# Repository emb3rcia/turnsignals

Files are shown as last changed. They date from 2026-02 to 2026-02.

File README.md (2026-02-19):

# turnsignals

Hello! This project is very simple, but to some people may be very needed, this is turnsignals module for PC steering wheels like logitech g29, made for HackClub's Blueprint program. It features USB-C (USB-FS standard) port for data and power and ESD protection on VBUS, DATA channels and CC channels! Firmware is given as whole STM32CubeIDE project. It is generated in STM32CubeMX and then the rest written in STM32CubeIDE

## Why i did this?

I want to get driving license soon. My biggest fear? Getting ticket for forgotting to signal a turn. My solution? Buy used PC steering wheel with pedals and gear shifter, make my own turnsignals and download some game where i can drive and use them. In this way i can make it my muscle memory.

# Images

Schematic

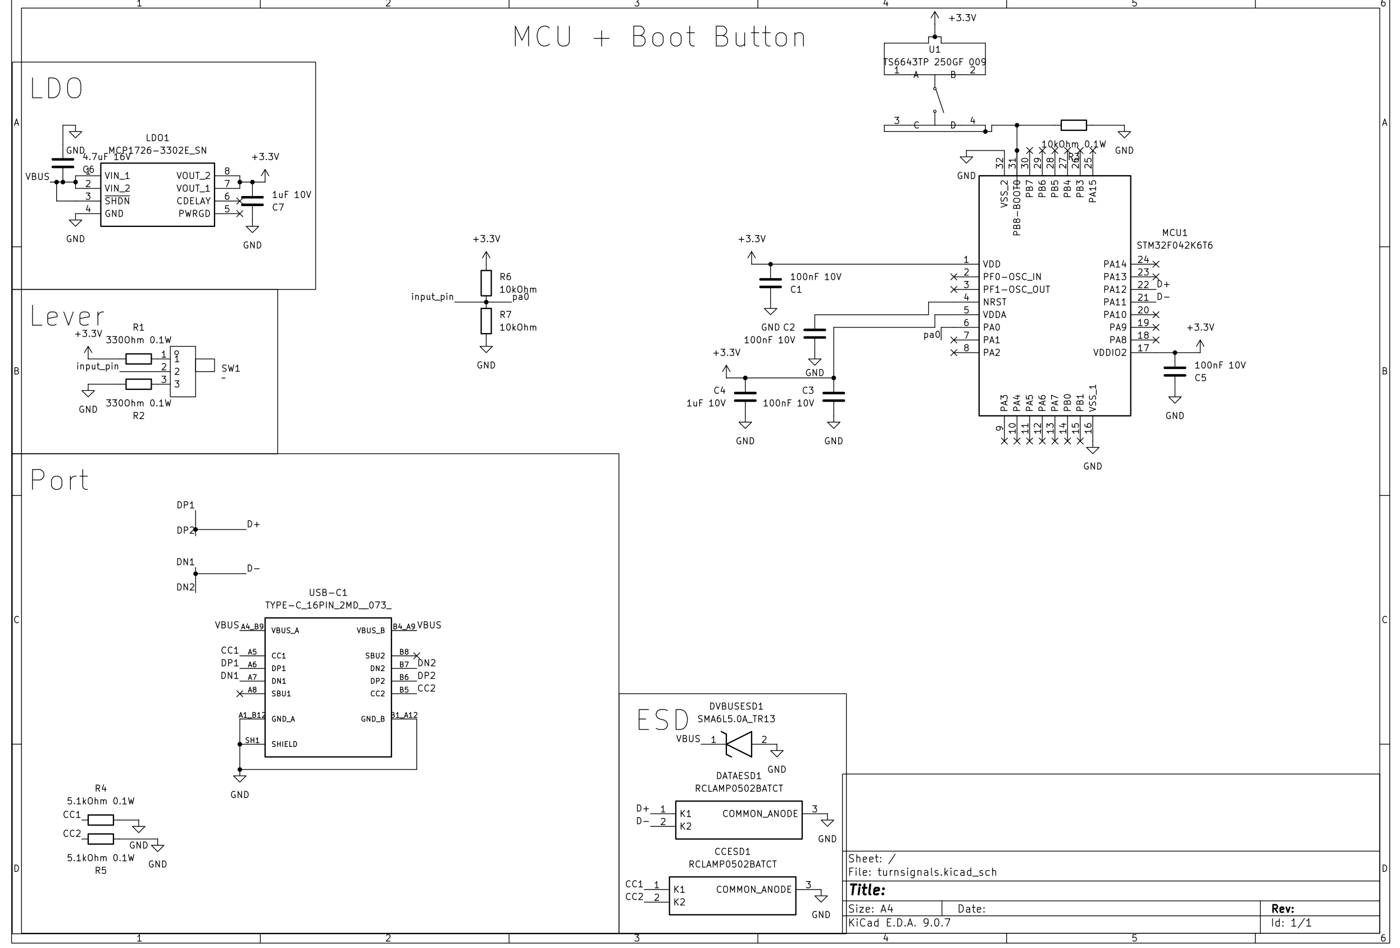
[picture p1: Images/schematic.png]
Schematic


PCB

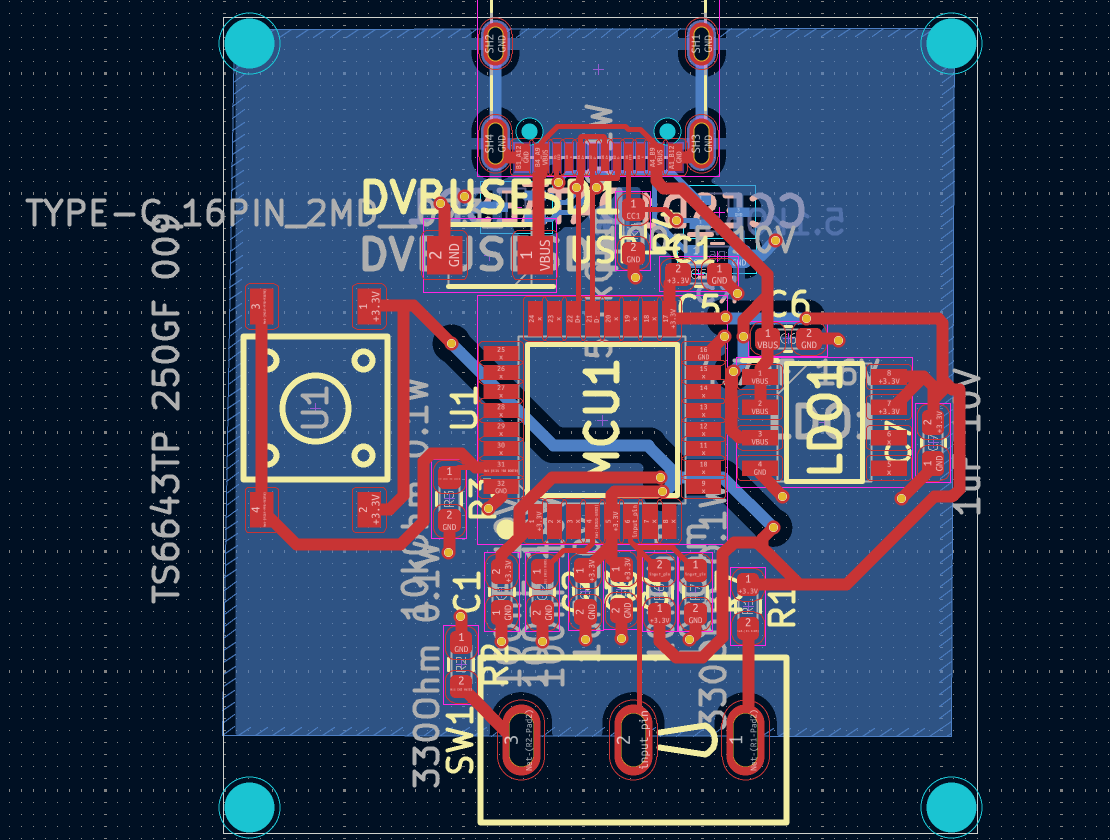
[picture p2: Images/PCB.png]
PCB


3D KiCad viewer

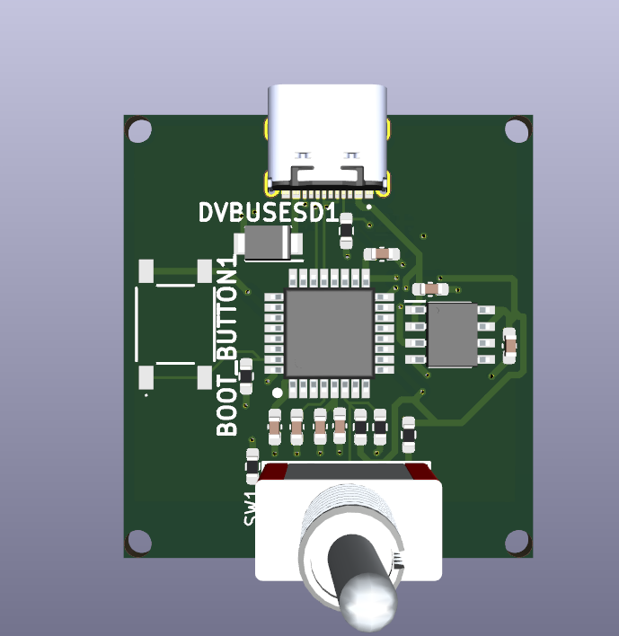
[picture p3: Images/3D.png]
3D


3D PCB

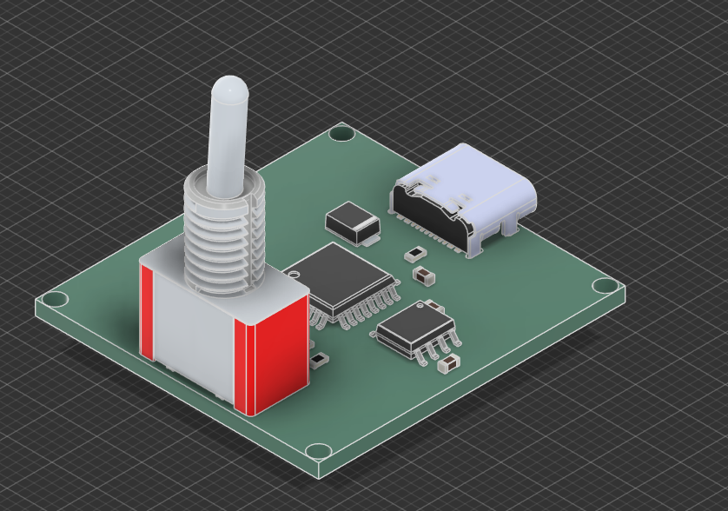
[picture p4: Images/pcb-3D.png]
3D PCB


3D Assembled

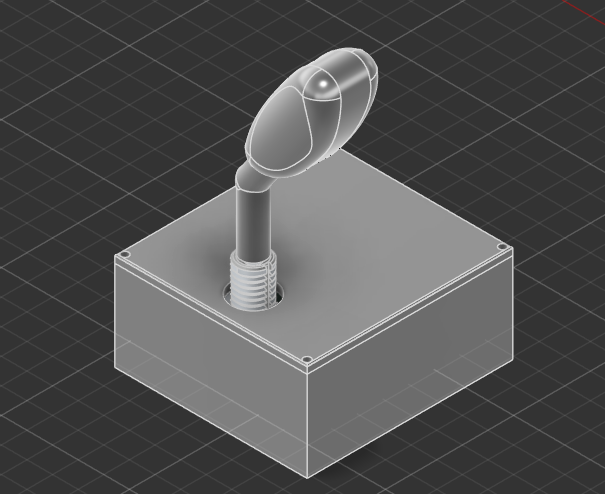
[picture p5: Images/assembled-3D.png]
3D Assembled


3D Lever

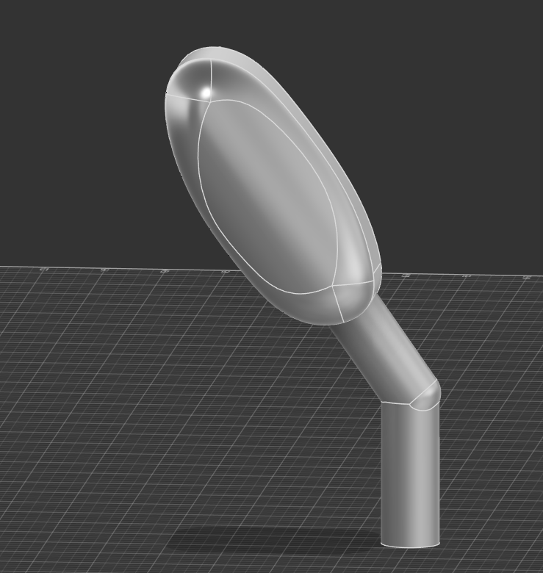
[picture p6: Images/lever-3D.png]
3D Lever


3D Case (top)

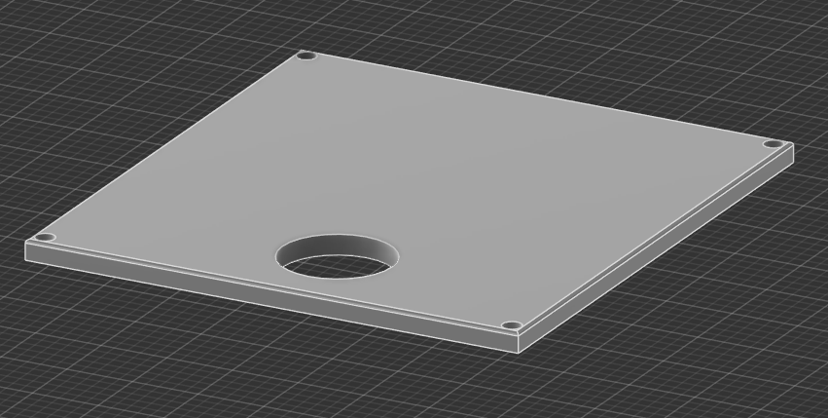
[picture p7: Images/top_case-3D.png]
3D Case


3D Case (bottom)
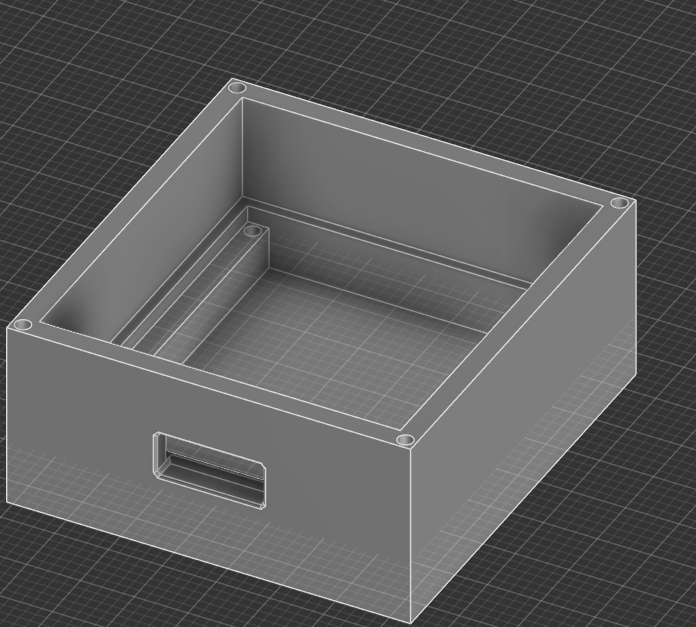
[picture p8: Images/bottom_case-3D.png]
3d Case


# Datasheets & part list
Here you can find datasheet for every part and exact part number for it i used:
- MCU: [STM Electronics STM32F042K6T6 LQFP-32 Package](Datasheets/STM32F042K6T6.pdf)
- USB-C Port: [SHOU HAN TYPE-C 16PIN 2MD(073)](Datasheets/TYPE-C-16PIN-2MD(073).pdf)
- DATA and CC lines ESD diodes: [Semtech RCLAMP0502BATCT](Datasheets/RCLAMP0502BATCT.pdf)
- VBUS line ESD diode: [Yageo SMA6L5.0A_TR13](Datasheets/SMA6L5.0A_TR13.pdf)
- 3.3V LDO: [Microchip MCP1726-3302E_SNVAO](Datasheets/MCP1726-3302E_SNVAO.pdf)
- 4.7uF 16V Capacitor: [Murata Electronics GRM188Z71C475KE21D](Datasheets/GRM188Z71C475KE21D.pdf)
- 1uF 10V Capacitor: Samsung Electro-Mechanics CL10A105KA8NNNC
- 100nF 10V Capacitor: [Vishay VJ0603Y104JXQCW1BC](Datasheets/VJ0603Y104JXQCW1BC.pdf)
- 5.1kOhm 0.1W Resistor: [Bourns CR0603-FX-5101ELF](Datasheets/CR0603-FX-5101ELF.pdf)
- 10Ohm 0.1W Resistor: [Vishay CRCW060310K0DHEAP](Datasheets/CRCW060310K0DHEAP.pdf)
- 300Ohm 0.1W Resistor: [GiantOhm GR0603J330RT5G00](Datasheets/GR0603J330RT5G00.pdf)
- BOOT button: [SHOU HAN TS6643TP 250gf 009](Datasheets/TS6643TP-250gf-009.pdf)
- Lever Toggle switch: [Dailywell 1MS1T1B1M1QES-5](Datasheets/1MS1T1B1M1QES-5.pdf)
# BOM
|Item |Description |Needed|Ordered|Why more/less? |Unit Price ($)|Total Price ($) |URL |
|---|---|---|---|---|---|---|---|
|ST STM32F042K6T6 |MCU |1 |1 |- |1.80$ |1.80$ |https://www.lcsc.com/product-detail/C69216.html |
|SEMTECH RCLAMP0502BATCT |CC and DATA lines esd |2 |0 |I have 3 left from other project |- |- |https://www.lcsc.com/product-detail/C117553.html |
|Littelfuse SMA6L5.0A |VBUS line esd |1 |1 |- |0.79$ |0.79$ |https://www.lcsc.com/product-detail/C1974860.html |
|MICROCHIP MCP1726-3302E/SN |3.3V LDO |1 |1 |- |2.22$ |2.22$ |https://www.lcsc.com/product-detail/C635928.html |
|muRata GRM188Z71C475KE21D |4.7uF capacitor |1 |0 |I have 9 left from other project |- |- |https://www.lcsc.com/product-detail/C389010.html |
|Samsung Electro-Mechanics CL10A105KA8NNNC|1uF capacitor |2 |50 |Minimal order size is 50 |0.0058$ |0.29$ |https://www.lcsc.com/product-detail/C5673.html |
|VISHAY VJ0603Y104JXQCW1BC |100nF decap capacitor |4 |5 |sold in increments of 5 |0.08$ |0.40$ |https://www.lcsc.com/product-detail/C3834925.html |
|SAMWHA CS1608X7R225K100NRB |2.2uF capacitor |2 |0 |I have 98 left from other project|- |- |https://www.lcsc.com/product-detail/C516003.html |
|BOURNS CR0603-FX-5101ELF |5.1kOhm 0.1w CC resistor |2 |0 |I have 8 left from other project |- |- |https://www.lcsc.com/product-detail/C2076779.html |
|VISHAY CRCW060310K0DHEAP |10kOhm pull-up/down resistor|2 |0 |I have 3 left from other project |- |- |https://www.lcsc.com/product-detail/C3917708.html |
|SHOU HAN TS6643TP 250gf 009 |BOOT and NRST button |2 |0 |I have 48 left from other project|- |- |https://www.lcsc.com/product-detail/C5342967.html |
|SHOU HAN TYPE-C 16PIN 2MD(073) |USB-C plug |1 |0 |I have 19 left from other project|- |- |https://www.lcsc.com/product-detail/C2765186.html |
|Shuntian PB1.6X4 |Mouting screws |4 |10 |minimal order size is 10 |0.04$ |0.42$ |https://www.lcsc.com/product-detail/C357374.html?s_z=n_1.6x4 |
|Dailywell 1MS1T1B1M1QES-5 |Lever Toggle switch |1 |1 |- |1.01$ |1.01$ |https://www.lcsc.com/product-detail/C496154.html?s_z=n_1MS1T1B1M1QES-5|
|PCB |PCB |1 |5 |5 is minimal order amount |- |2$+1.5$ delivery|https://jlcpcb.com/ |

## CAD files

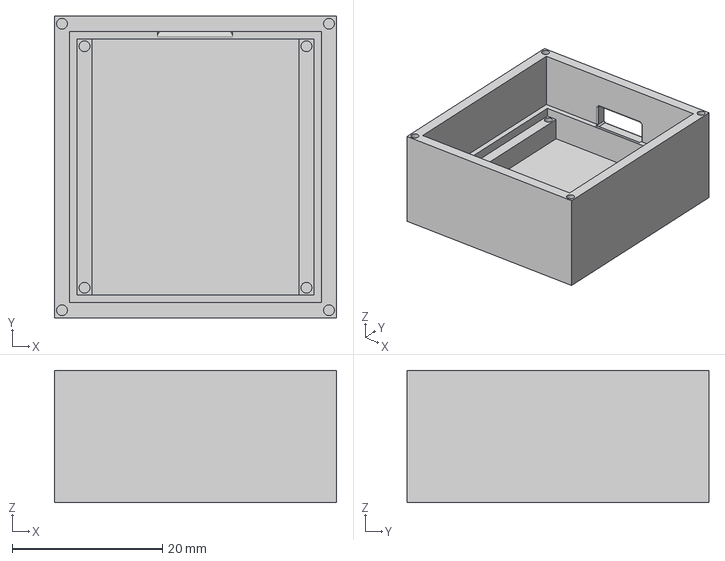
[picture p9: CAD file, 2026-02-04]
3D/bottom_case.step
37.5 x 40.1 x 17.6 mm

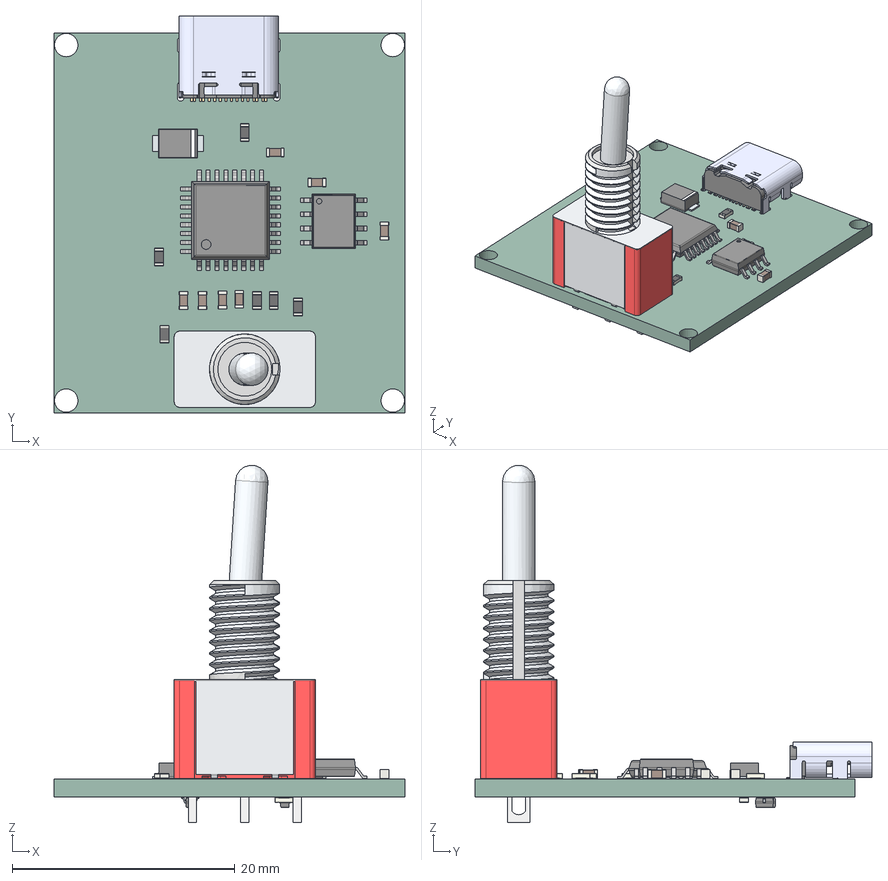
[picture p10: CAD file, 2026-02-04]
3D/pcb.step
31.5 x 35.6 x 32.1 mm
R_0603_1608Metric_1 x 7
C_0603_1608Metric_1 x 7
ASSEMBLY
ASSEMBLY_1
ASSEMBLY_2
TYPE-C 16PIN 2MD -073
toggle_switch_1ms1t1b1m1qes
ASSEMBLY_3 x 2
turnsignals_PCB

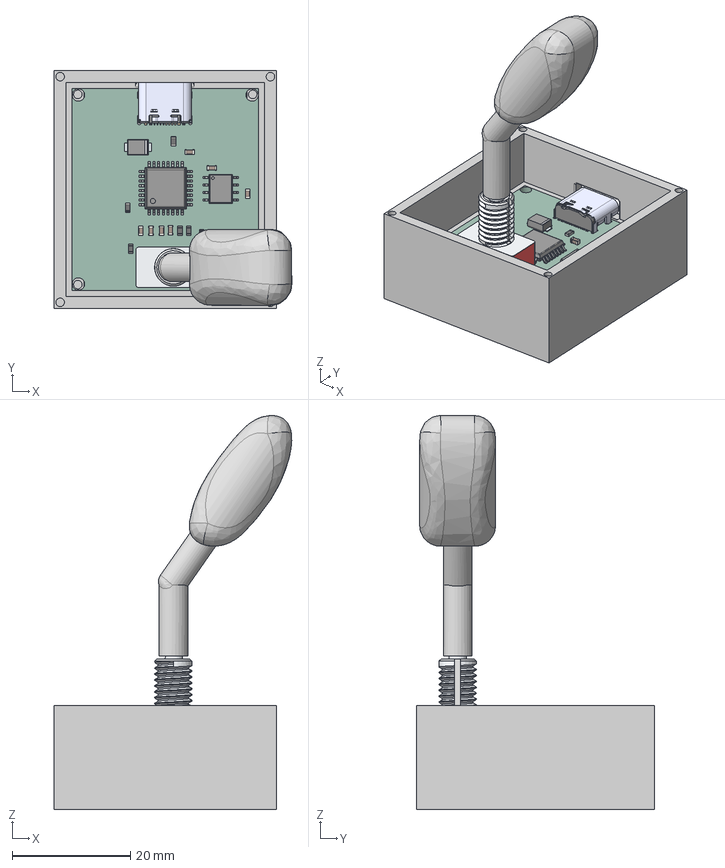
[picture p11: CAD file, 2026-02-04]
3D/turnsignals.step
40.2 x 40.1 x 66.6 mm
bottom_case
R_0603_1608Metric_1 x 7
C_0603_1608Metric_1 x 7
ASSEMBLY
ASSEMBLY_1
ASSEMBLY_2
TYPE-C 16PIN 2MD -073
toggle_switch_1ms1t1b1m1qes
ASSEMBLY_3 x 2
turnsignals_PCB
lever

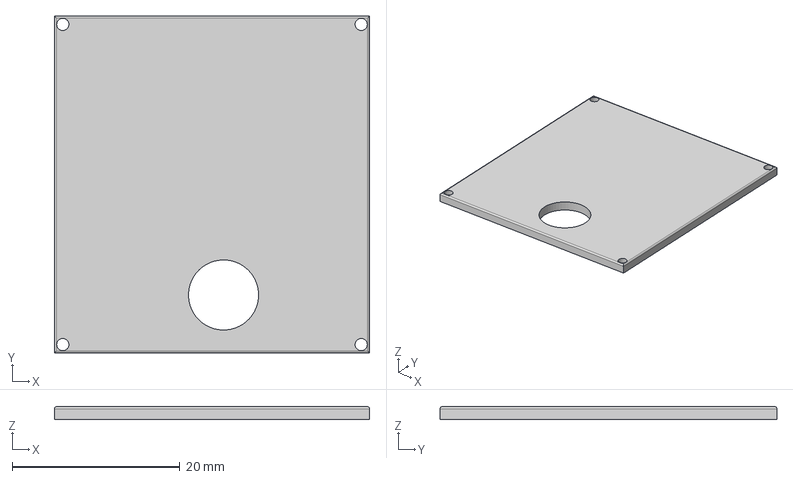
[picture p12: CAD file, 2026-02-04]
3D/top_case.step
37.5 x 40.1 x 1.50 mm

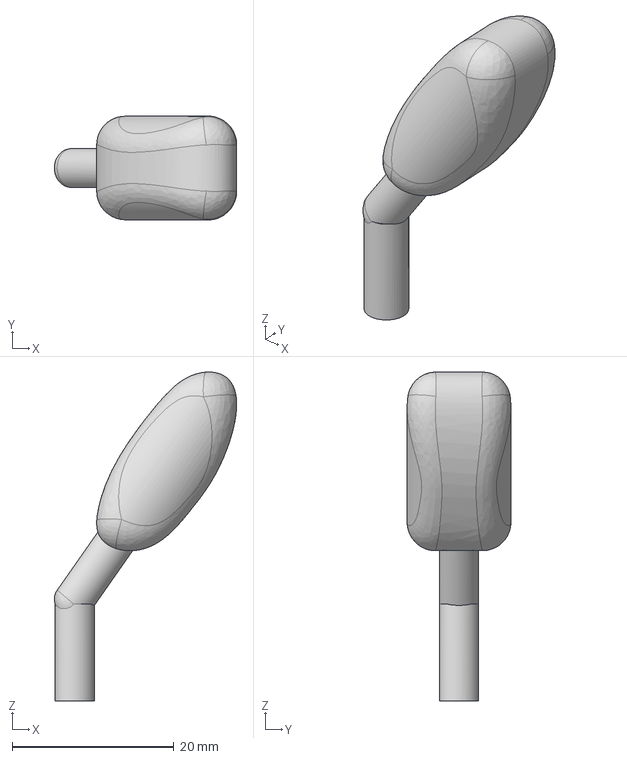
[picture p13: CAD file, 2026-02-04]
3D/lever.step
22.5 x 12.8 x 40.7 mm

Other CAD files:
3D/bottom_case.f3d
3D/lever.f3d
3D/pcb.f3d
3D/top_case.f3d

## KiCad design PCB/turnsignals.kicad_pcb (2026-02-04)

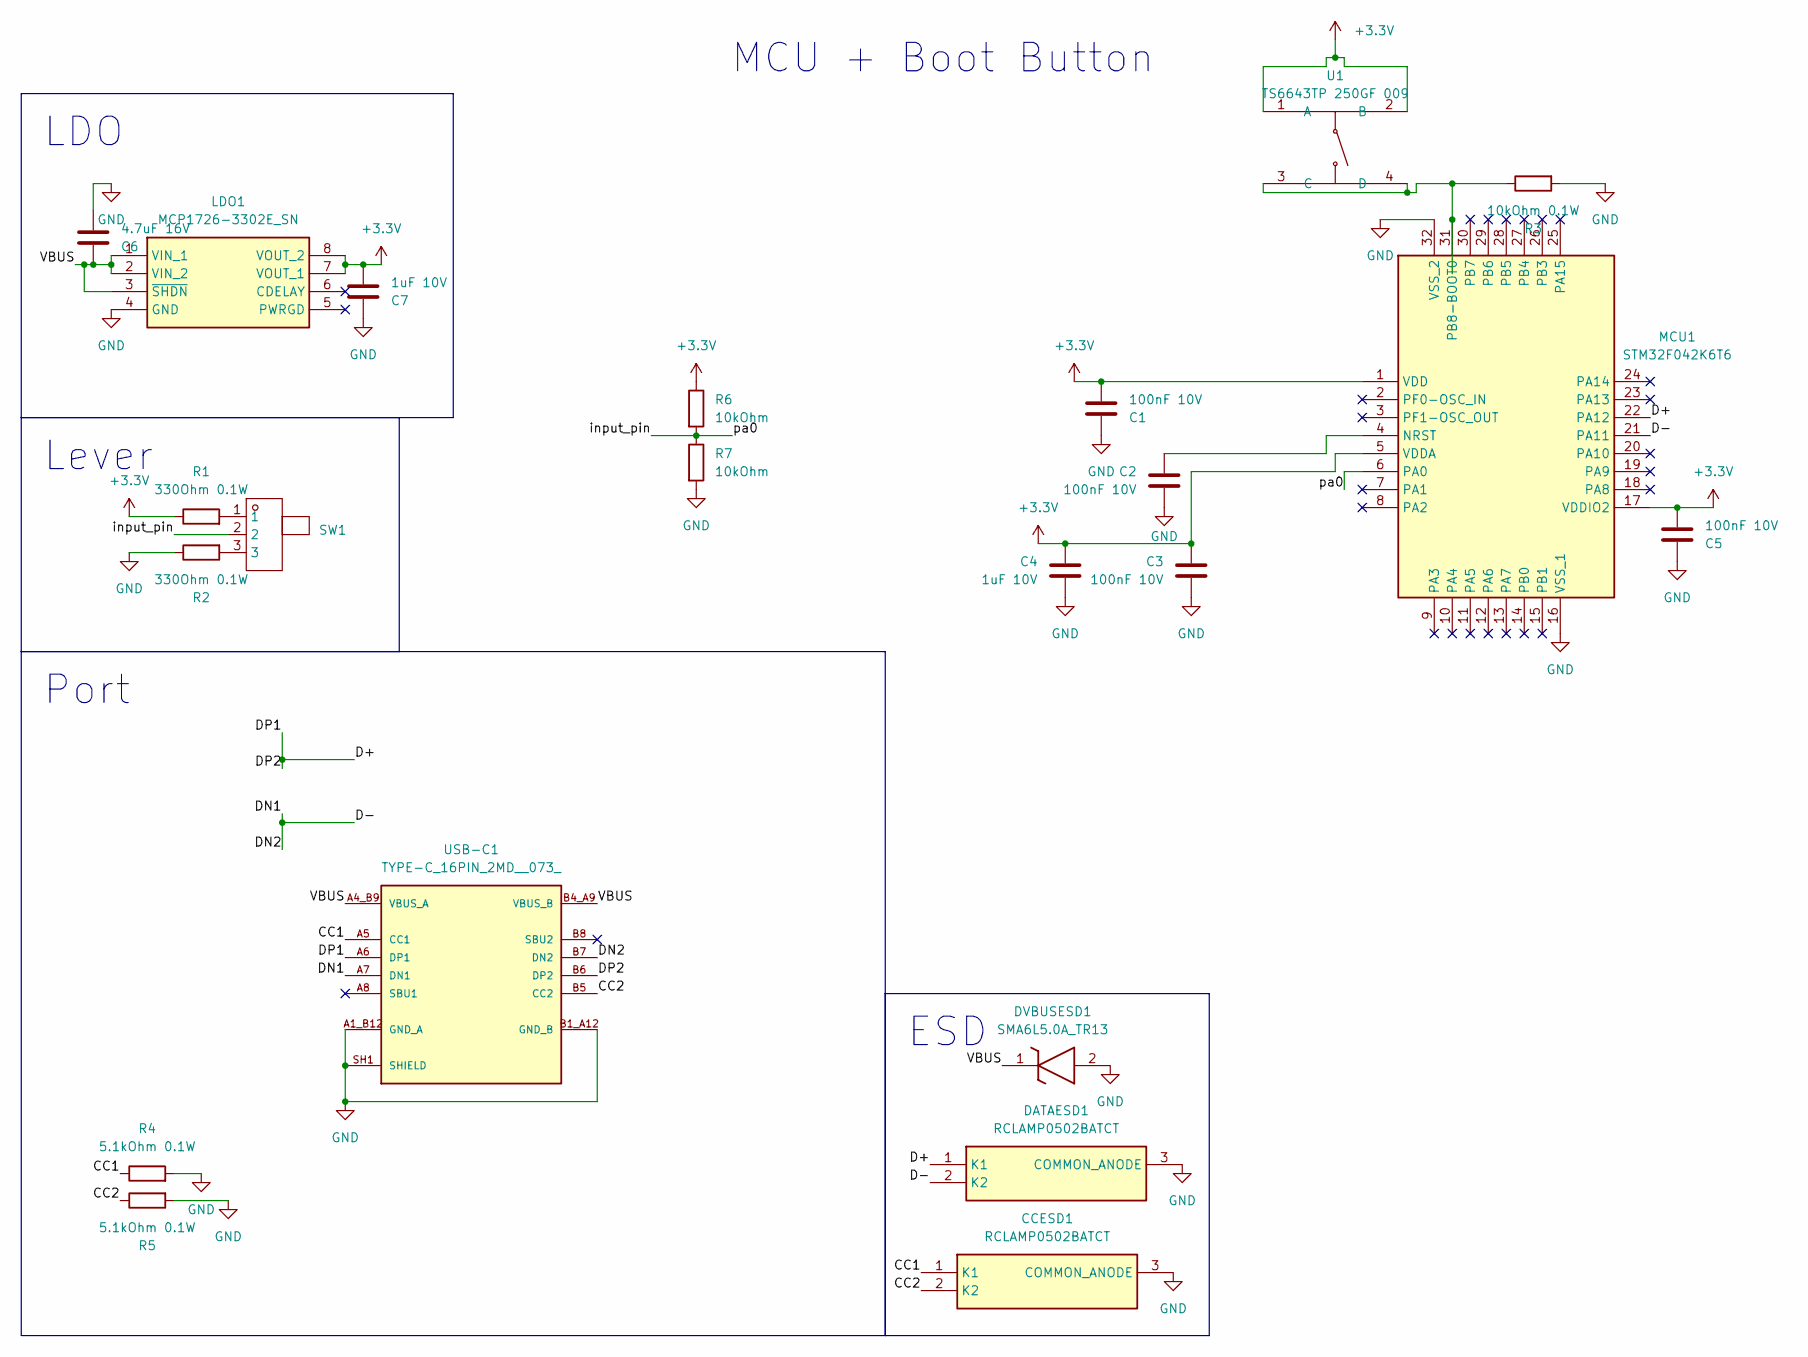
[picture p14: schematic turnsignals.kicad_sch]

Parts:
C1, C2, C3, C5: 100nF 10V; C_0603_1608Metric_Pad1.08x0.95mm_HandSolder
C4, C7: 1uF 10V; C_0603_1608Metric_Pad1.08x0.95mm_HandSolder
C6: 4.7uF 16V; C_0603_1608Metric_Pad1.08x0.95mm_HandSolder
CCESD1: RCLAMP0502BATCT; SOT50P160X90-3N; Manufacturer_Part_Number RCLAMP0502BATCT; Mouser Part Number 947-RCLAMP0502BATCT
DATAESD1: RCLAMP0502BATCT; SOT50P160X90-3N; Manufacturer_Part_Number RCLAMP0502BATCT; Mouser Part Number 947-RCLAMP0502BATCT
DVBUSESD1: SMA6L5.0A_TR13; SODFL4626X140N; Manufacturer_Part_Number SMA6L5.0A/TR13
LDO1: MCP1726-3302E_SN; SOIC127P600X175-8N; Manufacturer_Part_Number MCP1726-3302E/SN; Mouser Part Number 579-MCP1726-3302E/SN
MCU1: STM32F042K6T6; QFP80P900X900X160-32N; Manufacturer_Part_Number STM32F042K6T6; Mouser Part Number 511-STM32F042K6T6
R1, R2: 330Ohm 0.1W; R_0603_1608Metric_Pad0.98x0.95mm_HandSolder
R3: 10kOhm 0.1W; R_0603_1608Metric_Pad0.98x0.95mm_HandSolder
R4, R5: 5.1kOhm 0.1W; R_0603_1608Metric_Pad0.98x0.95mm_HandSolder
R6, R7: 10kOhm; R_0603_1608Metric_Pad0.98x0.95mm_HandSolder
SW1: SW-TH_1MS1T1B1M1QES-5
U1: TS6643TP 250GF 009; SW-SMD_4P-L6.2-W6.0-P4.50-LS9.0; LCSC Part C5342967
USB-C1: TYPE-C_16PIN_2MD__073_; SHOUHAN_TYPE-C_16PIN_2MD__073_; PARTREV A

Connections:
+3.3V: C1.2, C3.1, C4.1, C5.2, C7.2, LDO1.7 (VOUT_1), LDO1.8 (VOUT_2), MCU1.1 (VDD), MCU1.5 (VDDA), MCU1.17 (VDDIO2), R1.1, R6.1, U1.1 (A), U1.2 (B)
/CC1: CCESD1.1 (K1), R4.1, USB-C1.A5 (CC1)
/CC2: CCESD1.2 (K2), R5.1, USB-C1.B5 (CC2)
/D+: DATAESD1.1 (K1), MCU1.22 (PA12), USB-C1.A6 (DP1), USB-C1.B6 (DP2)
/D-: DATAESD1.2 (K2), MCU1.21 (PA11), USB-C1.A7 (DN1), USB-C1.B7 (DN2)
/VBUS: C6.1, DVBUSESD1.1 (K), LDO1.1 (VIN_1), LDO1.2 (VIN_2), LDO1.3 (~SHDN), USB-C1.A4_B9 (VBUS_A), USB-C1.B4_A9 (VBUS_B)
/input_pin: MCU1.6 (PA0), R6.2, R7.1, SW1.2
GND: C1.1, C2.2, C3.2, C4.2, C5.1, C6.2, C7.1, CCESD1.3 (COMMON_ANODE), DATAESD1.3 (COMMON_ANODE), DVBUSESD1.2 (A), LDO1.4 (GND), MCU1.16 (VSS_1), MCU1.32 (VSS_2), R2.1, R3.2, R4.2, R5.2, R7.2, USB-C1.A1_B12 (GND_A), USB-C1.B1_A12 (GND_B), USB-C1.SH1 (SHIELD), USB-C1.SH2 (SHIELD), USB-C1.SH3 (SHIELD), USB-C1.SH4 (SHIELD)
unnamed: C2.1, MCU1.4 (NRST)
unnamed: MCU1.31 (PB8-BOOT0), R3.1, U1.3 (C), U1.4 (D)
unnamed: R1.2, SW1.1
unnamed: R2.2, SW1.3

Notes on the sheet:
MCU + Boot Button
Port
ESD
LDO
Lever

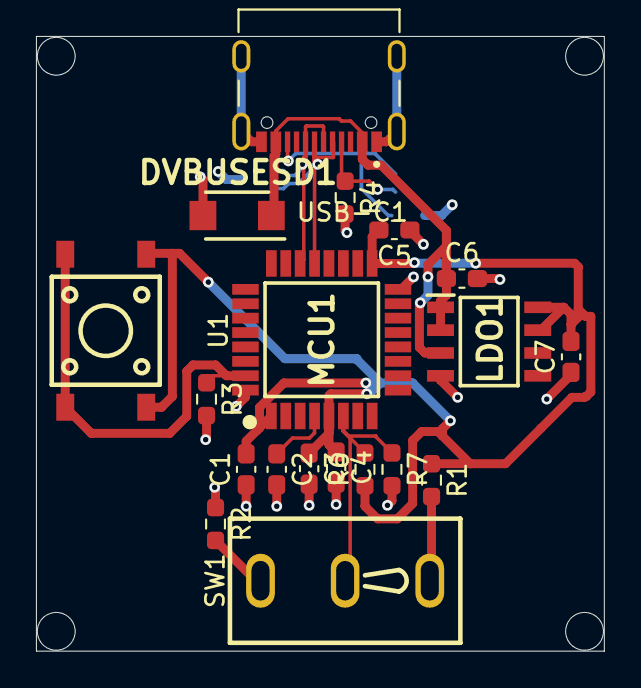
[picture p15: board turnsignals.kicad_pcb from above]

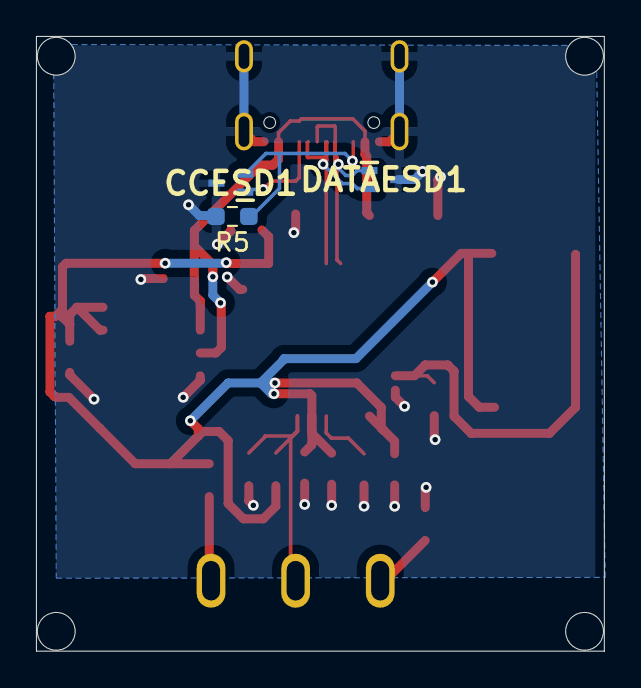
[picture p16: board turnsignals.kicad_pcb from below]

Board: 2 copper layers, 31.5 x 34.1 mm, 22 parts (3 on the bottom side), 12 nets.

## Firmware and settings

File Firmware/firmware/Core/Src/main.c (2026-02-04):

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
/* Includes ------------------------------------------------------------------*/
#include "main.h"
#include "usb_device.h"

ADC_HandleTypeDef hadc;
DMA_HandleTypeDef hdma_adc;

/* USER CODE BEGIN PV */
// i based this on chatgpt's example barebone code as it is my first stm32 project, but i did NOT copy it line for line, wanted to be transparent
#define ADC_LOW_THRESHOLD 1000
#define ADC_HIGH_THRESHOLD 3000
#define STABLE_COUNT 8
#define KEY_LOW 0x4F
#define KEY_HIGH 0x50

typedef enum {
	ADC_ZONE_MIDDLE = 0,
	ADC_ZONE_LOW,
	ADC_ZONE_HIGH
} adc_zone_t;

static adc_zone_t zone = ADC_ZONE_MIDDLE;
static uint8_t high_count = 0;
static uint8_t low_count  = 0;
static uint8_t middle_count = 0;

uint32_t value_adc;

/* USER CODE END PV */

void SystemClock_Config(void);
static void MX_GPIO_Init(void);
static void MX_DMA_Init(void);
static void MX_ADC_Init(void);
/* USER CODE BEGIN 0 */
void ADC_CheckZone(uint32_t adc)
{
	if (adc > ADC_HIGH_THRESHOLD)
	{
		high_count++;
		low_count = 0;
		middle_count = 0;

		if (high_count >= STABLE_COUNT && zone != ADC_ZONE_HIGH)
		{
			zone = ADC_ZONE_HIGH;
			high_count = 0;
			uint8_t HID_Report[8] = {0};
			HID_Report[2] = KEY_HIGH;
			USBD_HID_SendReport(&hUsbDeviceFS, HID_Report, sizeof(HID_Report));
		    HAL_Delay(10);
		    HID_Report[2] = 0;
		    USBD_HID_SendReport(&hUsbDeviceFS, HID_Report, sizeof(HID_Report));
		    HAL_Delay(10);
		}
	}
	else if (adc < ADC_LOW_THRESHOLD)
	{
		low_count++;
		high_count = 0;
		middle_count = 0;

		if (low_count >= STABLE_COUNT && zone != ADC_ZONE_LOW)
		{
			zone = ADC_ZONE_LOW;
			low_count = 0;
			uint8_t HID_Report[8] = {0};
			HID_Report[2] = KEY_LOW;
			USBD_HID_SendReport(&hUsbDeviceFS, HID_Report, sizeof(HID_Report));
		    HAL_Delay(10);
		    HID_Report[2] = 0;
		    USBD_HID_SendReport(&hUsbDeviceFS, HID_Report, sizeof(HID_Report));
		    HAL_Delay(10);
		}
	}
	else
	{
		middle_count++;
		high_count = 0;
		low_count = 0;

		if (middle_count >= STABLE_COUNT && zone != ADC_ZONE_MIDDLE)
		{
			if (zone == ADC_ZONE_HIGH)
			{
				uint8_t HID_Report[8] = {0};
				HID_Report[2] = KEY_HIGH;
				USBD_HID_SendReport(&hUsbDeviceFS, HID_Report, sizeof(HID_Report));
			    HAL_Delay(10);
			    HID_Report[2] = 0;
			    USBD_HID_SendReport(&hUsbDeviceFS, HID_Report, sizeof(HID_Report));
			    HAL_Delay(10);
			}
			else if (zone == ADC_ZONE_LOW)
			{
				uint8_t HID_Report[8] = {0};
				HID_Report[2] = KEY_LOW;
				USBD_HID_SendReport(&hUsbDeviceFS, HID_Report, sizeof(HID_Report));
				HAL_Delay(10);
				HID_Report[2] = 0;
				USBD_HID_SendReport(&hUsbDeviceFS, HID_Report, sizeof(HID_Report));
				HAL_Delay(10);
			}
			zone = ADC_ZONE_MIDDLE;
			middle_count = 0;

		}
	}
}
/* USER CODE END 0 */

/**
  * @brief  The application entry point.
  * @retval int
  */
int main(void)
{

  /* MCU Configuration--------------------------------------------------------*/

  /* Reset of all peripherals, Initializes the Flash interface and the Systick. */
  HAL_Init();

  /* Configure the system clock */
  SystemClock_Config();

  /* Initialize all configured peripherals */
  MX_GPIO_Init();
  MX_DMA_Init();
  MX_ADC_Init();
  MX_USB_DEVICE_Init();
  /* USER CODE BEGIN 2 */
  HAL_ADC_Start_DMA(&hadc, &value_adc, 1);
  /* USER CODE END 2 */

  /* Infinite loop */
  /* USER CODE BEGIN WHILE */
  while (1)
  {
	  ADC_CheckZone(value_adc);
	  HAL_Delay(10);
    /* USER CODE END WHILE */

    /* USER CODE BEGIN 3 */
  }
  /* USER CODE END 3 */
}

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


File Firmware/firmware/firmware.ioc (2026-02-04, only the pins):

Mcu.UserName=STM32F042K6Tx
PA0.Signal=ADC_IN0
PA11.Signal=USB_DM
PA12.Signal=USB_DP
PA13.Signal=SYS_SWDIO
PA14.Signal=SYS_SWCLK

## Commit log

2026-02-01 Added datasheets, images, pcb files, 3d files, BOM and readme
    [BOM.csv, turnsignals.kicad_pcb, turnsignals.kicad_sch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]
2026-02-01 added 3d files
    [bottom_case.step, lever.step, pcb.step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]
2026-02-01 updated 3d files
    [pcb.step, turnsignals.step]
2026-02-04 Corrected button wiring
    [BOM.csv, bottom_case.step, lever.step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]
2026-02-14 Added f3d files
    [bottom_case.f3d, lever.f3d, pcb.f3d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]
2026-02-19 Added gerbers
2026-02-19 Updated bom
    [BOM.csv]

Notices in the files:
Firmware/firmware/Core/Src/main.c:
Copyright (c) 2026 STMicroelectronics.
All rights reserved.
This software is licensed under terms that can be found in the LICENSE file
